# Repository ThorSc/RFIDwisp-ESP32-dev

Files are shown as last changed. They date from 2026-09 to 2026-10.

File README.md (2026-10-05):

# RFIDwisp on WT32-SC01 Plus

## Downloads

Prebuilt firmware is published as a release to the distribution repo
[`ThorSc/RFIDwisp-ESP32`](https://github.com/ThorSc/RFIDwisp-ESP32/releases/latest)
whenever a push to `master` carries a new `VERSION` (see "Releasing" below).
This repo is the source those releases are built from (see "License" below
for why it's public: two statically-linked dependencies are LGPL-2.1).

Standalone firmware for the WT32-SC01 Plus (ESP32-S3, 3.5" ST7796 touch
display) plus an external RC522 RFID module (SPI): a from-scratch, feature-equivalent
reimplementation of the [Flutter RFIDwisp app](../RFIDwisp-dev) that runs
without a PC, talking to Spoolman over Wi-Fi.

This is a reimplementation, not a port: Flutter cannot run on a bare
microcontroller (no Linux/GPU), so the UI is built with LVGL. The tag format
logic (`src/qidi_tag.h/.cpp`) is a manual C++ port of `filament_data.dart` /
`filament_spool.dart` and must be kept in sync if that format ever changes.

Being built feature by feature (see "Status" below); this is not a 1:1 UI
clone yet.

## Project layout

```
wt32sc01plus/
  platformio.ini        PlatformIO project (ESP32-S3, Arduino framework)
  include/lv_conf.h      LVGL configuration
  data/lang.example.json  Example UI string override (see "Language")
  src/
    board_config.h       Display/touch/RC522 pin assignments - check first
    display_setup.*       LovyanGFX + LVGL bring-up for the ST7796/FT6336
    mfrc522_reader.*        RC522 wrapper: find tag, authenticate, read/write
    qidi_tag.*              Material/colour/vendor tables + 16-byte encoding
    settings.*               Spoolman/OTA settings, in NVS
    strings.*                 UI text lookup with optional LittleFS override
    wifi_setup.*               Wi-Fi captive-portal provisioning
    ota_setup.*                 Wi-Fi (OTA) firmware updates
    updater.*                   Self-update from the GitHub releases
    ui.*                        LVGL screens (main, spool edit, settings)
    main.cpp                     Wires it all together
```

## Bill of materials

The parts list for building the terminal is in [`CAD/BOM.md`](CAD/BOM.md).

## Wiring

- **Display + touch**: on-board. The ST7796 display uses an 8-bit parallel
  (i80) bus, not SPI; the pins in `board_config.h` are verified against the
  board's datasheet and confirmed working on hardware.
- **RC522**: external module in SPI mode, wired to a *dedicated* SPI bus
  separate from the on-board display's i80 bus. Defaults in `board_config.h`
  (expansion header pins; GPIO 26-32 cannot be used on the ESP32-S3 -
  flash/PSRAM):
  - `RC522_SCK` = GPIO 12, `RC522_MISO` = GPIO 13, `RC522_MOSI` = GPIO 11,
    `RC522_SS` = GPIO 10
  - `RC522_RST` = GPIO 14, or tie the module's RST pin to 3.3V and set
    `RC522_RST` to `-1` if you don't want to wire it up.

## Building

Requires [PlatformIO](https://platformio.org/) (CLI or the VS Code
extension).

```
cd wt32sc01plus
pio run                # build
pio run -t upload      # flash over USB
pio run -t uploadfs    # flash data/ to LittleFS (only needed for a lang.json override)
pio device monitor      # serial log (115200 baud)
```

Once a device is on the network, later builds can also be flashed over Wi-Fi
instead of USB (see "OTA updates" below):

```
pio run -t upload --upload-port RFIDwisp-mobile.local
```

## First boot / Wi-Fi setup

On first boot (or after "Reconfigure network" in Settings), the device opens
a Wi-Fi access point named **RFIDwisp-Setup**. Join it from a phone or laptop;
a captive-portal page should open automatically (or browse to
`http://192.168.4.1`). Enter:

- your home Wi-Fi SSID and password,
- **Spoolman address** (e.g. `http://spoolman.local:7912`; leave empty to
  skip Spoolman - it can be turned back on/off later in Settings without
  re-running the portal).

The device reboots into your network. Wi-Fi credentials are stored by the
WiFiManager library in its own NVS namespace; the Spoolman
settings are stored separately (see `settings.h`) and are not erased by
"Reconfigure network" (only the Wi-Fi credentials are).

## OTA updates

Once connected to Wi-Fi, the device advertises itself as **RFIDwisp-mobile**
(hostname/mDNS name) and accepts firmware uploads over the network, so
later updates don't need a USB cable:

```
cd wt32sc01plus
pio run -t upload --upload-port RFIDwisp-mobile.local
```

This also works from the Arduino IDE: `RFIDwisp-mobile` should show up under
**Tools > Port** as a network port once the device is on the same network.

By default the OTA port has no password. To require one, set an "OTA update
password" in the Wi-Fi setup portal (join **RFIDwisp-Setup**, or run
"Reconfigure network" in Settings) alongside the Spoolman address; leave it
empty to keep OTA open. The password is stored in NVS (`settings.h`) like the
Spoolman address, and PlatformIO/Arduino will prompt for it on upload once
one is set.

## Updating from GitHub

At startup (if Wi-Fi is connected) the device checks the latest release of
[`ThorSc/RFIDwisp-ESP32`](https://github.com/ThorSc/RFIDwisp-ESP32/releases/latest)
and, if it is newer than the running firmware, asks whether to install it.
**Settings** has the same: a "Check at startup" switch and a button that checks
right away and then installs the version it found. The device downloads the
release's `RFIDwisp-ESP32-wt32sc01plus-firmware.bin` over TLS (certificates are
validated, the clock is set via NTP), verifies it against the SHA-256 GitHub
publishes and only then activates it and restarts. A failed or interrupted
download leaves the running firmware untouched. Releases published before this feature have no
such file and can only be flashed over USB/OTA as above; the first
self-updating version has to be flashed that way too.

## Language

All UI text goes through `T(StrId::...)` (see `src/strings.h`), never a
literal string, specifically so a language can be swapped without touching
UI code. English is built into the firmware (`src/strings.cpp`). To use a
different language, or to shrink the string table if flash is tight:

1. Copy `data/lang.example.json` to `data/lang.json` and translate the
   values (keep the keys unchanged; an entry can be omitted to keep the
   English default for that string).
2. `pio run -t uploadfs` to write it to the device's LittleFS partition.

No firmware rebuild needed to change or remove the override afterwards.

## What it does so far

- **Read tag**: waits for a tag, authenticates sector 1 with the same
  default-key list as the Flutter app (`FF FF FF FF FF FF`, all-zero, the
  MAD key, then `B0 B1 B2 B3 B4 B5`, each tried as key A then key B), reads
  the 16-byte payload from block 4, and shows it on the spool edit screen if
  it decodes to a known material/colour/vendor.
- **Write tag**: opens the spool edit screen (material, colour, vendor,
  spool number, weight as dropdowns/spinboxes), then writes the encoded 16
  bytes to block 4 and reads them back to confirm.
- **Settings screen**: shows Wi-Fi status and the configured Spoolman
  address, a "Use Spoolman" toggle, and "Reconfigure network".
- **Spoolman-integrated write/edit screen**: when Spoolman is active, the
  edit screen's Vendor + Spool number fields are replaced by a **Spool**
  selector ("New spool" + every cached Spoolman spool) and a **Spoolman
  vendor** dropdown, mirroring `rfid_tag_panel.dart`'s state machine:
  - Reading a tag tries to match its spool number against a cached Spoolman
    spool and points the Spool selector at it; otherwise it falls back to
    "New spool" with the tag's own fields (matches the Flutter app's
    behaviour for a tag written by something else, or before Spoolman knew
    about that spool number).
  - Picking an existing spool fills Material/Colour (best fuzzy match, ports
    of `closestQidiColor`/`qidiMaterialChoices`), Spoolman vendor and Weight
    from it and disables those fields (read-only, like the Flutter app).
  - Writing with "New spool" selected looks up a matching Spoolman filament
    (vendor + material + colour) and creates the spool via `POST
    /api/v1/spool`, using the new id as the tag's spool number; if no
    filament matches, or the create call fails, it falls back to a plain
    (Spoolman-unlinked) tag write and reports that in the status line -
    same "skip, don't fail" behaviour as `_createSpoolmanSpool`.

- **Filament dropdown** on the edit screen (Spoolman mode, "New spool" only):
  picking one of the cached Spoolman filaments prefills Material/Colour/
  Spoolman vendor from it (weight is still entered manually) - mirrors
  `rfid_tag_panel.dart`'s second dropdown for reusing an existing filament
  when creating a spool.

The UI runs in landscape (480x320).

Deliberately out of scope (per product decision): Moonraker / printer
integration (the Flutter app's QIDI Data panel and printer management), QR
code / PDF label printing (`qr_code_panel.dart`, `label_pdf.dart`,
`label_output.dart` - no printer or file export on this device), the
desktop window auto-sizer, and the GitHub-release update checker.

## Known limitations of the current state

- RC522 access and the Wi-Fi portal are synchronous: the touchscreen is
  unresponsive while either runs. Fine for the explicit, occasional actions
  they're used for so far; a background FreeRTOS task would be needed before
  adding anything longer-running.
- Display flashed and confirmed on hardware; RC522 wiring, touch and the
  Wi-Fi/Spoolman flows are not yet tested on the device - review pin
  assignments and library versions before relying on it.

## Releasing

Releases are published to the public [`ThorSc/RFIDwisp-ESP32`](https://github.com/ThorSc/RFIDwisp-ESP32)
repo by [`.github/workflows/release.yml`](.github/workflows/release.yml),
mirroring the pattern used by the sibling Flutter project's
`RFIDwisp-dev`/`RFIDwisp` repos: this source repo stays private, only built
firmware is published.

1. Bump the version in [`VERSION`](VERSION).
2. Push to `master`. If that version has no release yet in the distribution
   repo, the workflow builds the firmware and publishes it as a GitHub
   Release there (source commit tagged `v<version>` here too); if it already
   does, the run is a no-op.
3. To rebuild/re-upload an already-released version (e.g. after fixing a
   packaging issue), run the workflow manually from the Actions tab with
   "rebuild" ticked.

One-time setup this repo's Settings -> Secrets and variables -> Actions
needs before the first release: a secret named `RELEASES_REPO_TOKEN`
holding a classic GitHub PAT with the `public_repo` scope (see the comment
at the top of `release.yml` for why classic, not fine-grained).

## License

MIT, see [LICENSE](LICENSE). Bundled/linked third-party libraries keep their
own licenses (two are LGPL-2.1, statically linked) - see
[THIRD-PARTY-LICENSES.md](THIRD-PARTY-LICENSES.md).

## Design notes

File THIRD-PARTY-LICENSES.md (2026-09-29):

# Third-party licenses

This firmware (`wt32sc01plus/`) is built with [PlatformIO](https://platformio.org/)
on the Arduino framework for ESP32 and pulls in the libraries listed in
`wt32sc01plus/platformio.ini` (`lib_deps`). All of them end up statically
linked into the firmware binary. This file lists each one, its license, and
what that means for redistributing the built firmware.

| Component | Copyright | License |
|---|---|---|
| [Arduino core for ESP32](https://github.com/espressif/arduino-esp32) (Espressif Systems) | (c) Espressif Systems and contributors | LGPL-2.1-or-later |
| [Arduino_MFRC522v2](https://github.com/OSSLibraries/Arduino_MFRC522v2) | (c) OSSLibraries contributors | LGPL-2.1 |
| [LVGL](https://github.com/lvgl/lvgl) | (c) 2021 LVGL Kft | MIT |
| [ArduinoJson](https://github.com/bblanchon/ArduinoJson) | (c) 2014-2024 Benoit Blanchon | MIT |
| [WiFiManager](https://github.com/tzapu/WiFiManager) | (c) 2015 tzapu | MIT |
| [LovyanGFX](https://github.com/lovyan03/LovyanGFX) | (c) 2020 lovyan03; includes code from Adafruit_ILI9341 | MIT and BSD-2-Clause (FreeBSD License) |

## LGPL-2.1 components (Arduino-ESP32 core, Arduino_MFRC522v2)

These two are statically linked into `firmware.bin`, which LGPL-2.1 permits
for a device like this as long as the complete source needed to modify the
LGPL component and relink/rebuild the whole firmware is available - which it
is: this repository is public and `pio run` reproduces the exact build,
pinned to the library versions in `platformio.ini`/`platformio.lock`. If you
redistribute a modified build, keep that source available under the same
terms. Full license text: <https://www.gnu.org/licenses/old-licenses/lgpl-2.1.html>.

## MIT components (LVGL, ArduinoJson, WiFiManager, part of LovyanGFX)

```
Permission is hereby granted, free of charge, to any person obtaining a copy
of this software and associated documentation files (the "Software"), to deal
in the Software without restriction, including without limitation the rights
to use, copy, modify, merge, publish, distribute, sublicense, and/or sell
copies of the Software, and to permit persons to whom the Software is
furnished to do so, subject to the following conditions:

The above copyright notice and this permission notice shall be included in
all copies or substantial portions of the Software.

THE SOFTWARE IS PROVIDED "AS IS", WITHOUT WARRANTY OF ANY KIND, EXPRESS OR
IMPLIED, INCLUDING BUT NOT LIMITED TO THE WARRANTIES OF MERCHANTABILITY,
FITNESS FOR A PARTICULAR PURPOSE AND NONINFRINGEMENT. IN NO EVENT SHALL THE
AUTHORS OR COPYRIGHT HOLDERS BE LIABLE FOR ANY CLAIM, DAMAGES OR OTHER
LIABILITY, WHETHER IN AN ACTION OF CONTRACT, TORT OR OTHERWISE, ARISING FROM,
OUT OF OR IN CONNECTION WITH THE SOFTWARE OR THE USE OR OTHER DEALINGS IN
THE SOFTWARE.
```

## BSD-2-Clause / FreeBSD License component (part of LovyanGFX)

```
Redistribution and use in source and binary forms, with or without
modification, are permitted provided that the following conditions are met:

1. Redistributions of source code must retain the above copyright notice,
   this list of conditions and the following disclaimer.
2. Redistributions in binary form must reproduce the above copyright notice,
   this list of conditions and the following disclaimer in the documentation
   and/or other materials provided with the distribution.

THIS SOFTWARE IS PROVIDED BY THE COPYRIGHT HOLDERS AND CONTRIBUTORS "AS IS" AND
ANY EXPRESS OR IMPLIED WARRANTIES, INCLUDING, BUT NOT LIMITED TO, THE IMPLIED
WARRANTIES OF MERCHANTABILITY AND FITNESS FOR A PARTICULAR PURPOSE ARE
DISCLAIMED. IN NO EVENT SHALL THE COPYRIGHT OWNER OR CONTRIBUTORS BE LIABLE FOR
ANY DIRECT, INDIRECT, INCIDENTAL, SPECIAL, EXEMPLARY, OR CONSEQUENTIAL DAMAGES
(INCLUDING, BUT NOT LIMITED TO, PROCUREMENT OF SUBSTITUTE GOODS OR SERVICES;
LOSS OF USE, DATA, OR PROFITS; OR BUSINESS INTERRUPTION) HOWEVER CAUSED AND
ON ANY THEORY OF LIABILITY, WHETHER IN CONTRACT, STRICT LIABILITY, OR TORT
(INCLUDING NEGLIGENCE OR OTHERWISE) ARISING IN ANY WAY OUT OF THE USE OF THIS
SOFTWARE, EVEN IF ADVISED OF THE POSSIBILITY OF SUCH DAMAGE.
```

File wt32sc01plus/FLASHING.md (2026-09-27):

# Flashing a release

Each release contains four files that must all be flashed together, at
fixed offsets (this partition table reserves two OTA app slots, so the
board also needs `boot_app0.bin` to know which one to boot):

| File | Flash offset |
|---|---|
| `bootloader.bin` | `0x0` |
| `partitions.bin` | `0x8000` |
| `boot_app0.bin` | `0xe000` |
| `firmware.bin` | `0x10000` |

## Using esptool

1. Install [esptool](https://github.com/espressif/esptool): `pip install esptool`.
2. Put the WT32-SC01 Plus into bootloader mode (hold BOOT, tap RESET, release
   BOOT - exact buttons depend on your board revision) and note its serial
   port (e.g. `COM5` on Windows, `/dev/ttyUSB0` on Linux).
3. From the folder the four files were extracted into:

   ```
   esptool.py --chip esp32s3 --port <PORT> --baud 460800 write_flash \
     0x0 bootloader.bin \
     0x8000 partitions.bin \
     0xe000 boot_app0.bin \
     0x10000 firmware.bin
   ```

## Using PlatformIO instead

If you have the source checked out and PlatformIO installed, `pio run -t
upload` flashes all of this automatically at the right offsets - no need to
handle the four files by hand.

## Wi-Fi setup

After flashing, the device opens a **RFIDwisp-Setup** Wi-Fi access point on
first boot. See the main README ("First boot / Wi-Fi setup") for the
captive-portal steps.

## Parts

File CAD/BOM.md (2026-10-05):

What do you need to build the RFID wisp terminal?

1. 1 x WT32-SC01PLUS (Wireless-Tag Technology Co., Limited)
1. 1 x RC522 RFID Module (MFRC-522)
1. 1 x KCD11 2 Pin 10x15mm Mini Push Button Switch
1. 1 x USB Jack 3.1 Type-C 4 P Welding Wire 3A Female DIY Connector Straight
1. 1 x USB 3.1 Type C Male/Female Connectors Jack Tail 24pin USB Male Plug
1. 1 x 3mm LED blue
1. 1 x R680 Ohm resistor
1. Wires AWG24 for connection between WT32 and RC522
1. Wires AWG18 or 0.75mm² for power lines

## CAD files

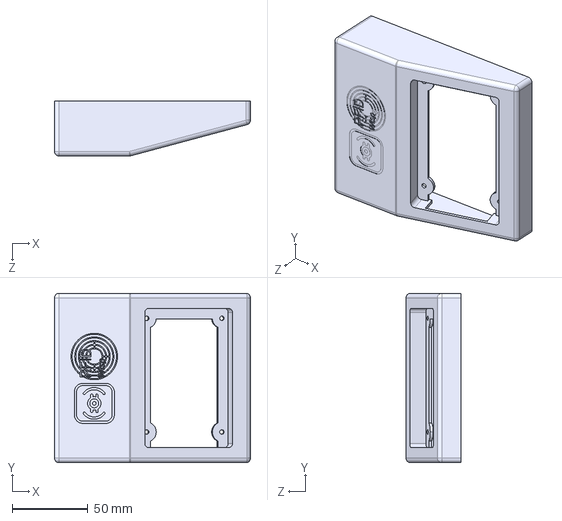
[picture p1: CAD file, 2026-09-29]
CAD/Cover.STEP
129.5 x 112.0 x 36.3 mm

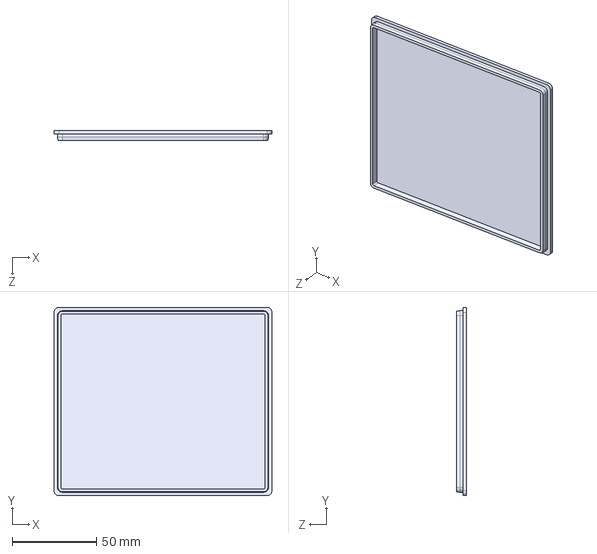
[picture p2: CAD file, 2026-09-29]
CAD/Base.STEP
129.5 x 112.0 x 6.00 mm

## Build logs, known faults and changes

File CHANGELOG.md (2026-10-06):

# Changelog

All notable changes to the RFID Wisp Terminal (WT32-SC01 Plus firmware) are
documented in this file. The version is the one in `VERSION`.

The format is based on [Keep a Changelog](https://keepachangelog.com/en/1.1.0/),
and this project adheres to [Semantic Versioning](https://semver.org/).

## [Unreleased]

## [0.6.2] - 2026-10-06

### Fixed

- Firmware update: after "Install" (or "Check now") the screen now shows the
  "installing" overlay with the progress bar right away. The download used to
  run inside the touch event handler, where LVGL does not redraw, so the display
  looked frozen until the device restarted.

## [0.6.1] - 2026-10-05

### Changed

- Tag byte 2 is synchronised with the RFIDwisp app: it holds the QIDI vendor code.
  Reading keeps the QIDI vendor of a tag that also has a Spoolman vendor (only an
  unknown byte 2 with byte 13 set, i.e. older tags, reads as GENERIC), the edit
  screen shows it, and a re-write in Spoolman mode keeps it.
- The material list is the 43 entries of the current Plus4 / Max4 / Q2 firmware,
  identical to RFIDwisp.

### Added

- Host tests (`pio test -e native`) that run the tag vectors shared with RFIDwisp.
- Bill of materials for the terminal in `CAD/BOM.md`.

## [0.6.0] - 2026-09-30

### Added

- Firmware self-update from GitHub releases: the latest release is checked at
  startup (switchable) and from Settings, the user is asked before installing,
  the firmware is downloaded over validated TLS, its SHA-256 is verified and it
  is flashed to the other OTA slot. Releases now also carry the bare
  `firmware.bin` the device downloads.

### Fixed

- Settings screen: more compact layout, the update status line no longer overlaps
  the button.

## [0.5.4] - 2026-09-29

### Changed

- App title is now "RFID Wisp Terminal".

## [0.5.3] - 2026-09-29

### Changed

- App title changed to "RFID Wisp ESP32 Terminal" (replaced again in 0.5.4).

## [0.5.2] - 2026-09-29

### Changed

- The Filament dropdown is sorted by vendor, material, colour, like in the app.

## [0.5.1] - 2026-09-29

### Changed

- The Spool dropdown shows the newest Spoolman spool first, like in the app.

## [0.5.0] - 2026-09-29

### Added

- OTA firmware updates over Wi-Fi.
- The hostname is `RFIDwisp-mobile`.

## [0.4.0] - 2026-09-28

### Changed

- The RFID reader is an RC522 over SPI instead of the PN532 over I2C
  (library: Arduino_MFRC522v2). **The wiring changes**, see the README.

## [0.3.0] - 2026-09-27

### Added

- Screen sleep: the backlight turns off after a configurable idle time
  (Settings, 0–60 min, 0 = never); the waking touch is not passed on to the UI.
- Picking a Spoolman filament for a new spool fixes material, colour and Spoolman
  vendor (only the weight stays editable); that filament is used as it is when
  the spool is created.
- The firmware version is shown next to the title.

## [0.2.0] - 2026-09-27

### Added

- Colour pickers: the Spool and Filament lists show each entry's colour;
  selecting a spool also selects its filament, and a filament sets the colour
  (8-digit RRGGBBAA Spoolman colours are recognised).
- Validation before writing: weight 0–10000, Spoolman vendor ID ≤ 255, spool
  number ≤ 999 (checked before a spool is created in Spoolman).

### Changed

- Landscape UI (480×320) with all screens re-laid out; write screen with four
  rows, colour button and colour grid, numeric keypad overlay for number fields,
  Spoolman address editable in Settings.
- Byte 2 holds only the QIDI vendor (0 GENERIC / 1 QIDI); the Spoolman vendor
  stays in byte 13.
- The Moonraker client, the QIDI Data screen and the printer management were removed.

### Fixed

- The display uses the board's 8-bit parallel bus (it was wrongly driven as SPI);
  the reader pins were corrected.
- Spoolman float weights are read correctly (the remaining weight showed as 0)
  and the weight is shown in the spool list.

## [0.1.0] - 2026-09-26

### Added

- First version: standalone ESP32-S3 / LVGL reimplementation of the RFIDwisp app
  for the WT32-SC01 Plus. Tag read and write, spool creation in Spoolman and
  Wi-Fi setup through a captive portal.

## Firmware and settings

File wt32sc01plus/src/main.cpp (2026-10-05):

#include <Arduino.h>
#include <WiFi.h>
#include <vector>
#include "display_setup.h"
#include "mfrc522_reader.h"
#include "ota_setup.h"
#include "qidi_tag.h"
#include "settings.h"
#include "spoolman_client.h"
#include "strings.h"
#include "ui.h"
#include "updater.h"
#include "wifi_setup.h"

static Mfrc522Reader reader;

// Cached Spoolman data, refreshed whenever the write screen (or a tag read)
// is about to show it. filaments is only used internally here (matching a
// new spool to link); vendors/spools are also handed to the UI for its
// dropdowns.
static std::vector<SpoolmanVendor> spoolmanVendors;
static std::vector<SpoolmanFilament> spoolmanFilaments;
static std::vector<SpoolmanSpool> spoolmanSpools;

// The spool number of the last tag read, if any - used as a fallback when
// writing a "new" spool that no longer matches any cached Spoolman filament
// (mirrors rfid_tag_panel.dart's "Spoolman skipped" path for a re-write).
static int lastReadSpoolNumber = -1;

// The QIDI vendor code (byte 2) of the last tag read, if any. Spoolman mode has
// no QIDI vendor dropdown (its row shows the Spoolman vendor), so a re-write
// keeps what the tag had instead of silently changing it.
static int lastReadVendorCode = -1;

static bool spoolmanActive() {
  return settings.useSpoolman && settings.spoolmanAddress.length() > 0;
}

// Reloads the Spoolman caches and pushes them to the UI; returns whether
// Spoolman mode should be active (false also on a load failure, so the form
// falls back to plain manual entry rather than showing stale/empty lists).
static bool refreshSpoolmanData() {
  if (!spoolmanActive()) return false;

  uiSetStatus(T(StrId::LoadingSpoolmanData));
  displayLoop();

  SpoolmanResult result = spoolmanGetVendors(settings.spoolmanAddress, spoolmanVendors);
  if (result.ok) result = spoolmanGetFilaments(settings.spoolmanAddress, spoolmanFilaments);
  if (result.ok) result = spoolmanGetSpools(settings.spoolmanAddress, spoolmanSpools);
  if (!result.ok) {
    uiSetStatus((String(T(StrId::SpoolmanLoadFailed)) + " " + result.error).c_str());
    return false;
  }

  uiSetSpoolmanLists(spoolmanVendors, spoolmanSpools, spoolmanFilaments);
  return true;
}

static const char *tagResultMessage(TagResult result) {
  switch (result) {
    case TagResult::Ok: return "OK";
    case TagResult::NoTag: return T(StrId::ErrorNoTag);
    case TagResult::NotMifareClassic1k: return T(StrId::ErrorNotClassic1k);
    case TagResult::AuthenticationFailed: return T(StrId::ErrorAuthFailed);
    case TagResult::ReadFailed: return T(StrId::ErrorReadFailed);
    case TagResult::WriteFailed: return T(StrId::ErrorWriteFailed);
  }
  return "";
}

// Called by the UI's "Read tag" button. Blocking: the display will not
// update again until this returns, which is fine for a single explicit
// user action but would need a background task for anything longer-running.
void handleReadTagRequested() {
  uiSetStatus(T(StrId::StatusHoldTag));
  displayLoop();

  if (!reader.waitForTag(3000)) {
    uiSetStatus(tagResultMessage(TagResult::NoTag));
    return;
  }

  uint8_t raw[qidiTagLength];
  TagResult result = reader.readSpoolBytes(raw);
  if (result != TagResult::Ok) {
    uiSetStatus(tagResultMessage(result));
    return;
  }

  FilamentSpool spool;
  if (FilamentSpool::isBlankTagBytes(raw)) {
    uiSetStatus(T(StrId::TagBlank));
    return;
  }
  if (!FilamentSpool::fromTagBytes(raw, spool)) {
    uiSetStatus(T(StrId::ErrorUnknownTag));
    return;
  }

  lastReadSpoolNumber = spool.spoolNumber > 0 ? spool.spoolNumber : -1;
  lastReadVendorCode = spool.vendorCode;
  bool active = refreshSpoolmanData();
  uiSetSpoolmanMode(active);

  if (active || !spoolmanActive()) uiSetStatus(T(StrId::TagRead));
  uiShowSpool(spool);
}

// Called by the main screen's "Write tag" button, before the edit screen is
// shown - refreshes the Spoolman lists (if active) so the Spool selector is
// current, then hands off to the UI.
void handleWriteScreenOpened() {
  lastReadSpoolNumber = -1;
  lastReadVendorCode = -1;
  bool active = refreshSpoolmanData();
  uiSetSpoolmanMode(active);
  if (active || !spoolmanActive()) uiSetStatus(T(StrId::Ready));
  uiShowEditScreenForWrite();
}

// Resolves the Spoolman side of a write: for an existing spool, just reuses
// its id/vendor; for a new one, tries to link it to a matching filament and
// create it in Spoolman, falling back to a plain (unlinked) tag write if
// that is not possible. No-op if Spoolman is not active.
static void resolveSpoolmanFields(FilamentSpool &spool) {
  if (!spoolmanActive()) return;

  if (!uiIsNewSpoolSelected()) {
    int id = uiSelectedExistingSpoolId();
    int vendorId = uiSelectedSpoolmanVendorId();
    spool.spoolNumber = id > 0 ? (uint16_t)id : 0;
    spool.internalVendorId = vendorId > 0 ? (uint8_t)vendorId : 0;
    return;
  }

  int vendorId = uiSelectedSpoolmanVendorId();
  // A filament picked by the user is used as it is; otherwise look one up
  // from vendor + material + colour.
  int filamentId = uiSelectedFilamentId();
  if (filamentId < 0 && vendorId >= 0) {
    filamentId = findFilamentId(spoolmanFilaments, vendorId, qidiMaterialName(spool.materialCode),
                                qidiColorHex(spool.colorCode));
  }

  if (filamentId < 0) {
    uiSetStatus(T(StrId::SpoolmanSkipped));
    spool.spoolNumber = lastReadSpoolNumber > 0 ? (uint16_t)lastReadSpoolNumber : 0;
    spool.internalVendorId = 0;
    return;
  }

  int newId;
  SpoolmanResult result =
      spoolmanCreateSpool(settings.spoolmanAddress, filamentId, spool.lastWeightGrams, newId);
  if (!result.ok) {
    uiSetStatus((String(T(StrId::SpoolmanCreateFailed)) + ": " + result.error).c_str());
    spool.spoolNumber = lastReadSpoolNumber > 0 ? (uint16_t)lastReadSpoolNumber : 0;
    spool.internalVendorId = 0;
    return;
  }

  spool.spoolNumber = (uint16_t)newId;
  spool.internalVendorId = (uint8_t)vendorId;
  uiSetStatus(T(StrId::SpoolCreated));
}

// Called by the edit screen's "Write tag" button.
// Limits of what fits on the tag, as enforced by the PC app
// (filament_spool.dart / rfid_tag_panel.dart). Checked before anything is
// created in Spoolman, so a rejected write leaves no orphan spool behind.
static bool validateBeforeSpoolman(const FilamentSpool &spool) {
  if (spool.lastWeightGrams > 10000) {
    uiSetStatus(T(StrId::ErrorWeightRange));
    return false;
  }
  if (!spoolmanActive()) return true;

  int vendorId = uiSelectedSpoolmanVendorId();
  if (vendorId > 255) {
    uiSetStatus((String(T(StrId::ErrorVendorIdRange)) + " " + vendorId).c_str());
    return false;
  }
  int spoolId = uiSelectedExistingSpoolId();
  if (spoolId > 999) {
    uiSetStatus((String(T(StrId::ErrorSpoolNumberRange)) + " #" + spoolId).c_str());
    return false;
  }
  return true;
}

void handleWriteTagRequested() {
  FilamentSpool spool = uiCurrentSpool();
  if (!validateBeforeSpoolman(spool)) return;
  resolveSpoolmanFields(spool);
  // Byte 2 only ever holds the QIDI vendor (0 = GENERIC, 1 = QIDI); the
  // Spoolman vendor lives in byte 13. Spoolman mode has no QIDI vendor
  // dropdown: a re-write keeps the vendor of the tag that was read, a fresh
  // tag gets GENERIC if linked to a Spoolman vendor (a third-party spool) and
  // QIDI otherwise.
  if (spoolmanActive()) {
    spool.vendorCode = lastReadVendorCode >= 0
                           ? (uint8_t)lastReadVendorCode
                           : qidiVendorCode(spool.internalVendorId != 0 ? "GENERIC" : "QIDI");
  }
  if (spool.spoolNumber > 999) {
    // A newly created spool got a number that does not fit; it exists in
    // Spoolman already, but the tag cannot hold it.
    uiSetStatus((String(T(StrId::ErrorSpoolNumberRange)) + " #" + spool.spoolNumber).c_str());
    return;
  }

  uiSetStatus(T(StrId::StatusHoldTag));
  displayLoop();

  if (!reader.waitForTag(3000)) {
    uiSetStatus(tagResultMessage(TagResult::NoTag));
    return;
  }

  uint8_t raw[qidiTagLength];
  spool.toTagBytes(raw);
  TagResult result = reader.writeSpoolBytes(raw);
  uiSetStatus(result == TagResult::Ok ? T(StrId::TagWritten) : tagResultMessage(result));
}

// The newer firmware found by the last check, if any.
static bool updateAvailable = false;
static UpdateInfo pendingUpdate;

static String firmwareLine() { return String(T(StrId::Firmware)) + " v" + firmwareVersion(); }

// Shows the outcome of a check on the settings screen: the button installs
// the found version, or checks again.
static void showUpdateState(const String &status) {
  String button = updateAvailable ? String(T(StrId::UpdateInstall)) + " v" + pendingUpdate.version
                                  : String(T(StrId::UpdateCheckNow));
  uiSetUpdateState(status.c_str(), button.c_str());
}

// Asks GitHub for a newer firmware and updates the settings screen. With
// [prompt] a found update is also offered in a dialog (the startup check);
// the settings button only reports it, the user is at the button already.
static void checkForUpdate(bool prompt) {
  uiShowBusy(T(StrId::UpdateChecking));
  displayLoop();

  String error;
  UpdateCheck result = updateCheck(pendingUpdate, error);
  uiHideBusy();

  updateAvailable = result == UpdateCheck::Available;
  switch (result) {
    case UpdateCheck::Available:
      showUpdateState(String(T(StrId::UpdateAvailable)) + " v" + pendingUpdate.version);
      if (prompt) uiShowUpdatePrompt(pendingUpdate.version.c_str());
      break;
    case UpdateCheck::UpToDate:
      showUpdateState(firmwareLine() + " - " + T(StrId::UpdateUpToDate));
      break;
    case UpdateCheck::Failed:
      showUpdateState(String(T(StrId::UpdateCheckFailed)) + " " + error);
      break;
  }
}

static void onUpdateProgress(int percent) {
  uiShowBusy(T(StrId::UpdateInstalling), percent);
  displayLoop();
}

// Downloads and flashes the update found by the last check; restarts the
// device on success.
static void installUpdate() {
  if (!updateAvailable) return;
  uiShowBusy(T(StrId::UpdateInstalling), 0);
  displayLoop();

  String error;
  bool ok = updateInstall(pendingUpdate, onUpdateProgress, error);
  uiHideBusy();
  if (!ok) showUpdateState(String(T(StrId::UpdateInstallFailed)) + " " + error);
}

// The UI callbacks only record what was asked for. Checking and installing
// block for a long time and redraw the screen themselves (displayLoop), which
// LVGL ignores while it is still inside the event handler that started them:
// the "installing" overlay would never show up. loop() runs them instead.
enum class UpdateAction { None, Check, Install };
static UpdateAction pendingAction = UpdateAction::None;

// The settings screen's update button: install what was found, else check.
void handleUpdateButtonPressed() {
  pendingAction = updateAvailable ? UpdateAction::Install : UpdateAction::Check;
}

void handleInstallUpdateRequested() { pendingAction = UpdateAction::Install; }

static void runPendingUpdateAction() {
  UpdateAction action = pendingAction;
  pendingAction = UpdateAction::None;
  if (action == UpdateAction::Check) checkForUpdate(false);
  if (action == UpdateAction::Install) installUpdate();
}

static bool wifiConnected = false;

static void connectWifi() {
  uiSetStatus("Connecting to Wi-Fi...");
  displayLoop();

  bool connected = wifiSetupConnect();
  if (connected) {
    String info = String(T(StrId::WifiStatus)) + ": " + WiFi.SSID() + " (" +
                  WiFi.localIP().toString() + ")";
    uiSetWifiStatus(info.c_str());
    otaSetup();
    wifiConnected = true;
  } else {
    uiSetWifiStatus("Not connected - join \"RFIDwisp-Setup\" to configure.");
  }
}

void setup() {
  Serial.begin(115200);

  stringsInit();
  settings.load();

  displaySetup();
  displaySetSleepTimeout(settings.sleepMinutes);
  uiInit();

  connectWifi();

  if (!reader.begin()) {
    uiSetStatus(T(StrId::Rc522NotFound));
  } else {
    uiSetStatus(T(StrId::Ready));
  }

  if (wifiConnected && settings.checkForUpdates) checkForUpdate(true);
}

void loop() {
  displayLoop();
  runPendingUpdateAction();
  otaLoop();
  delay(5);
}

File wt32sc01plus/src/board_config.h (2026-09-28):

#pragma once

// -----------------------------------------------------------------------
// WT32-SC01 Plus on-board display: ST7796, 320x480, 8-bit parallel (i80)
// interface - NOT SPI. Touch: FT6336 (FT5x06 protocol) on I2C.
// These are the values used by the community LovyanGFX configs for this
// board; if the display stays blank, compare against your board's schematic.
// -----------------------------------------------------------------------
#define TFT_WR 47
#define TFT_RD -1
#define TFT_RS 0 // DC
#define TFT_D0 9
#define TFT_D1 46
#define TFT_D2 3
#define TFT_D3 8
#define TFT_D4 18
#define TFT_D5 17
#define TFT_D6 16
#define TFT_D7 15
#define TFT_RST 4
#define TFT_BL 45

#define TOUCH_SDA 6
#define TOUCH_SCL 5
#define TOUCH_INT 7
#define TOUCH_RST -1 // shares the display reset line

// Native panel orientation is portrait; the UI runs rotated to landscape.
#define PANEL_WIDTH 320
#define PANEL_HEIGHT 480
#define SCREEN_WIDTH 480
#define SCREEN_HEIGHT 320

// -----------------------------------------------------------------------
// RC522 wiring (external module, SPI mode) on a dedicated SPI bus, separate
// from the on-board display's i80 bus. GPIO 26-32 are used by flash/PSRAM on
// the ESP32-S3 and cannot be used; 10-14 are on the board's expansion
// header. Re-check against your board's silkscreen.
//
// RST is optional: tie the module's RST pin to 3.3V instead and set
// RC522_RST to -1 if you don't want to wire it up.
// -----------------------------------------------------------------------
#define RC522_SCK 12
#define RC522_MISO 13
#define RC522_MOSI 11
#define RC522_SS 10
#define RC522_RST 14

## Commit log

2026-09-26 Initial commit: WT32-SC01 Plus firmware for RFIDwisp
    Standalone ESP32-S3/LVGL reimplementation of the Flutter RFIDwisp app:
    PN532 tag read/write, Moonraker QIDI Data view, Spoolman-linked spool
    creation, multi-printer settings and Wi-Fi captive-portal provisioning.
2026-09-26 Add release workflow publishing to the public RFIDwisp-ESP32 repo
    Mirrors RFIDwisp-dev's dev/distribution split: VERSION gates whether a
    push builds and publishes a release, softprops/action-gh-release
    uploads the firmware bundle cross-repo via a RELEASES_REPO_TOKEN PAT.
2026-09-27 Landscape UI, correct WT32-SC01 Plus pins, drop Moonraker, rework write screen
    - Display uses the board's 8-bit parallel bus (was wrongly SPI); PN532 moved
    to GPIO 10/11; UI rotated to 480x320 landscape and all screens re-laid out.
    - Remove the Moonraker client, QIDI Data screen and printer management.
    - Write screen: 4-row layout (Spool/Filament, Material/Color, Spoolman
    vendor/Spool number, Weight), colour button + colour grid, numeric keypad
    overlay for number fields, Spoolman address editable in Settings.
    - Fix Spoolman float weights (remaining weight showed as 0) and show it in
    the spool list.
    [board_config.h, display_setup.cpp, main.cpp]
2026-09-27 Colour pickers, Spoolman sync and tag write validation
    - Spool and Filament pickers show each entry's colour; selecting a spool
    also selects its filament, and a filament syncs Color (8-digit RRGGBBAA
    Spoolman colours are now recognised).
    - Validate before writing: weight 0-10000, Spoolman vendor ID <= 255,
    spool number <= 999, checked before a spool is created in Spoolman.
    - Byte 2 only holds the QIDI vendor (0 GENERIC / 1 QIDI); the Spoolman
    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
2026-09-27 Add screen sleep and lock fields to the chosen filament
    - Backlight turns off after a configurable idle time (Settings, 0-60 min,
    0 = never); the waking touch is not passed on to the UI.
    - Picking a Spoolman filament for a new spool fixes material, colour and
    Spoolman vendor (only the weight stays editable) and that filament is
    used as it is when the spool is created.
    [display_setup.cpp, main.cpp]
2026-09-28 Release 0.4.0: switch RFID reader from PN532 to RC522 (SPI)
    Replaces the Adafruit_PN532/I2C reader with an RC522 over SPI, using
    the OSSLibraries/Arduino_MFRC522v2 library.
    [board_config.h, main.cpp, mfrc522_reader.cpp]
2026-09-29 Add case CAD files (Base, Cover)
    [Base.STEP, Cover.STEP]
2026-09-29 Add MIT LICENSE and third-party license notices
    Matches the sibling RFIDwisp-dev Flutter app's MIT licensing. Notes the two
    LGPL-2.1 dependencies (Arduino-ESP32 core, Arduino_MFRC522v2) that are
    statically linked into the firmware binary.
2026-09-29 Update docs: source repo is now public (LGPL-2.1 compliance)
    The Arduino-ESP32 core and Arduino_MFRC522v2 are LGPL-2.1 and statically
    linked into the firmware; satisfying LGPL-2.1 §6 for a binary-only release
    requires the full application source to be available for relinking, not
    just a reference to the upstream libraries. Made this repo public instead
    of a written 3-year source-on-request offer.
2026-09-29 README: fix stale PN532 references, project uses RC522 over SPI
    The reader was switched from PN532 (I2C) to RC522 (SPI) in 0.4.0 but the
    README wasn't updated to match - it still described I2C wiring/pins and
    named the old pn532_reader.* source files.
2026-09-29 ui: show newest Spoolman spool first in the Spool dropdown
    Matches the Flutter app's existing spool dropdown order (highest id / most
    recently created first). The Filament dropdown is left as-is (insertion
    order, per Spoolman's API response) on request.
2026-09-29 ui: sort the Filament dropdown by vendor, material, colour
    Matches the Flutter app's filament dropdown order, on request.
2026-09-29 Release 0.5.2: sort Filament dropdown by vendor, material, colour
2026-09-29 Change app title to "RFID Wisp ESP32 Terminal"
2026-09-29 Release 0.5.3: change app title to "RFID Wisp ESP32 Terminal"
2026-09-30 Release 0.6.0: firmware self-update from GitHub releases
    Checks the latest release at startup (switchable) and from Settings, asks
    before installing, downloads over validated TLS, verifies the SHA-256 and
    flashes the other OTA slot. The release now also carries the bare
    firmware.bin the device downloads.
2026-09-30 Settings screen: compact the layout so the update status line no longer overlaps the button
2026-10-05 Sync tag byte 2 with RFIDwisp and add host tests with shared tag vectors
    Reading no longer forces GENERIC when a Spoolman vendor is set: byte 2 is the
    QIDI vendor code, only an unknown byte 2 with byte 13 set (older tags) reads as
    GENERIC. The edit screen shows the tag's vendor. In Spoolman mode a re-write
    keeps the vendor of the tag that was read.
    qidi_tag.h no longer includes Arduino.h. `pio test -e native` runs
    test/tag_vectors.json, an identical copy of RFIDwisp's
    test/fixtures/tag_vectors.json, against the C++ port.
    [main.cpp]
2026-10-05 Update the QIDI material list to the current printer firmware
    Same 43 materials and names as RFIDwisp's filament_data.dart (from the
    officiall_filas_list.cfg of Plus4, Max4 and Q2); tag_vectors.json copied over.
2026-10-05 Add bill of materials for the terminal
2026-10-05 README: point to the bill of materials in CAD/BOM.md
2026-10-05 Release 0.6.1: tag byte 2 synchronised with RFIDwisp, current material list
    Reading keeps the QIDI vendor of a tag that also has a Spoolman vendor, the
    edit screen shows it, and a re-write in Spoolman mode keeps it. The material
    list is the 43 entries of the current Plus4/Max4/Q2 firmware.
2026-10-05 Fix missing feedback when installing a firmware update; add CHANGELOG.md
    The update ran inside the LVGL touch handler, where the busy overlay is never
    redrawn. loop() now runs the check/install. The changelog is published in the
    release zip and in the root of the distribution repo (without Unreleased).
    [main.cpp]
